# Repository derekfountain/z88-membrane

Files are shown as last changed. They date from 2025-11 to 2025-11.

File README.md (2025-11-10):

# A new keyboard membrane for the Z88 laptop

The Z88 laptop from 1988 is well out of support. :)
I have a couple of them, and although they're working fine, I've
always been a bit nervous of that keyboard membrane. Membranes on
machines like the ZX Spectrum have a finite life and need replacing
every so often. Would the Z88's keyboard membrane be the same?

I decided to create a new one using a flexi-PCB. I wasn't sure if this
approach would work, but I wanted to find out. So, with considerable
help from my friend Andrew Menadue, I made one. Here it is:

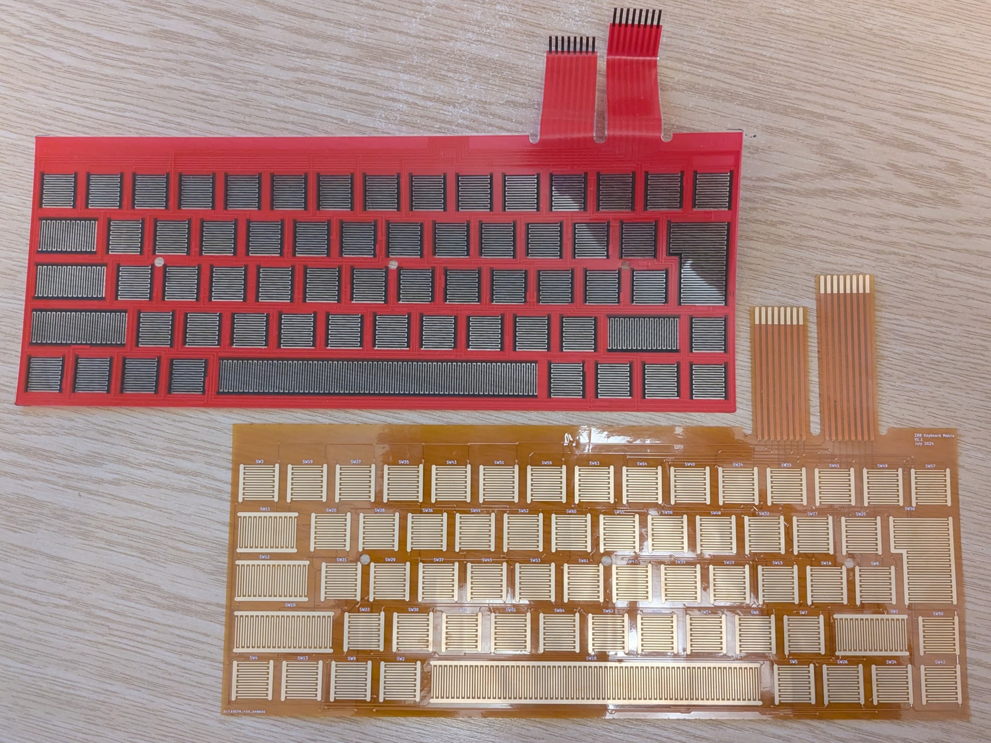
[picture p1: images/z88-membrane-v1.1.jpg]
v1.1


The original is the red one, the new one, as created by JLCPCB, is the
orange one.

The photo is of v1.1, which has the keyboard tails. v1.0 didn't have those,
which was a bit of an oversight. There are no stiffners on the tails. I
didn't know how to create them. It works without stiffners, but
you need to hold the tail right up at the gold fingers and wiggle it into
the connector. Stiffners will be added to v1.2, should I make one.

It works well, sitting perfectly in place under the Z88 rubber mat, and
conducting the carbon under-surface just as expected.

I had mine made from 0.2mm flexi-PCB, which is as thick as JLCPCB can make
them. It could stand being a bit thicker, if possible. It's a little bit
floppy compared to the original one.

[Derek Fountain](https://www.derekfountain.org/), November 2025

# Acknowledgements

[Andrew Menadue](http://trochilidae.blogspot.com/) for doing the clever
KiCAD footprint thing and the original layout of the keys.

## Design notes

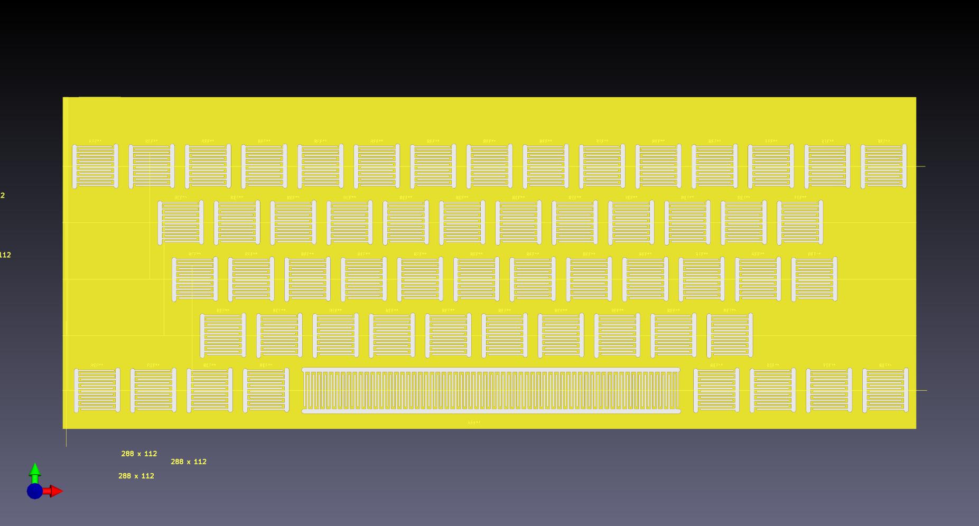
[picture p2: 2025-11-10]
images/membrane1.jpg

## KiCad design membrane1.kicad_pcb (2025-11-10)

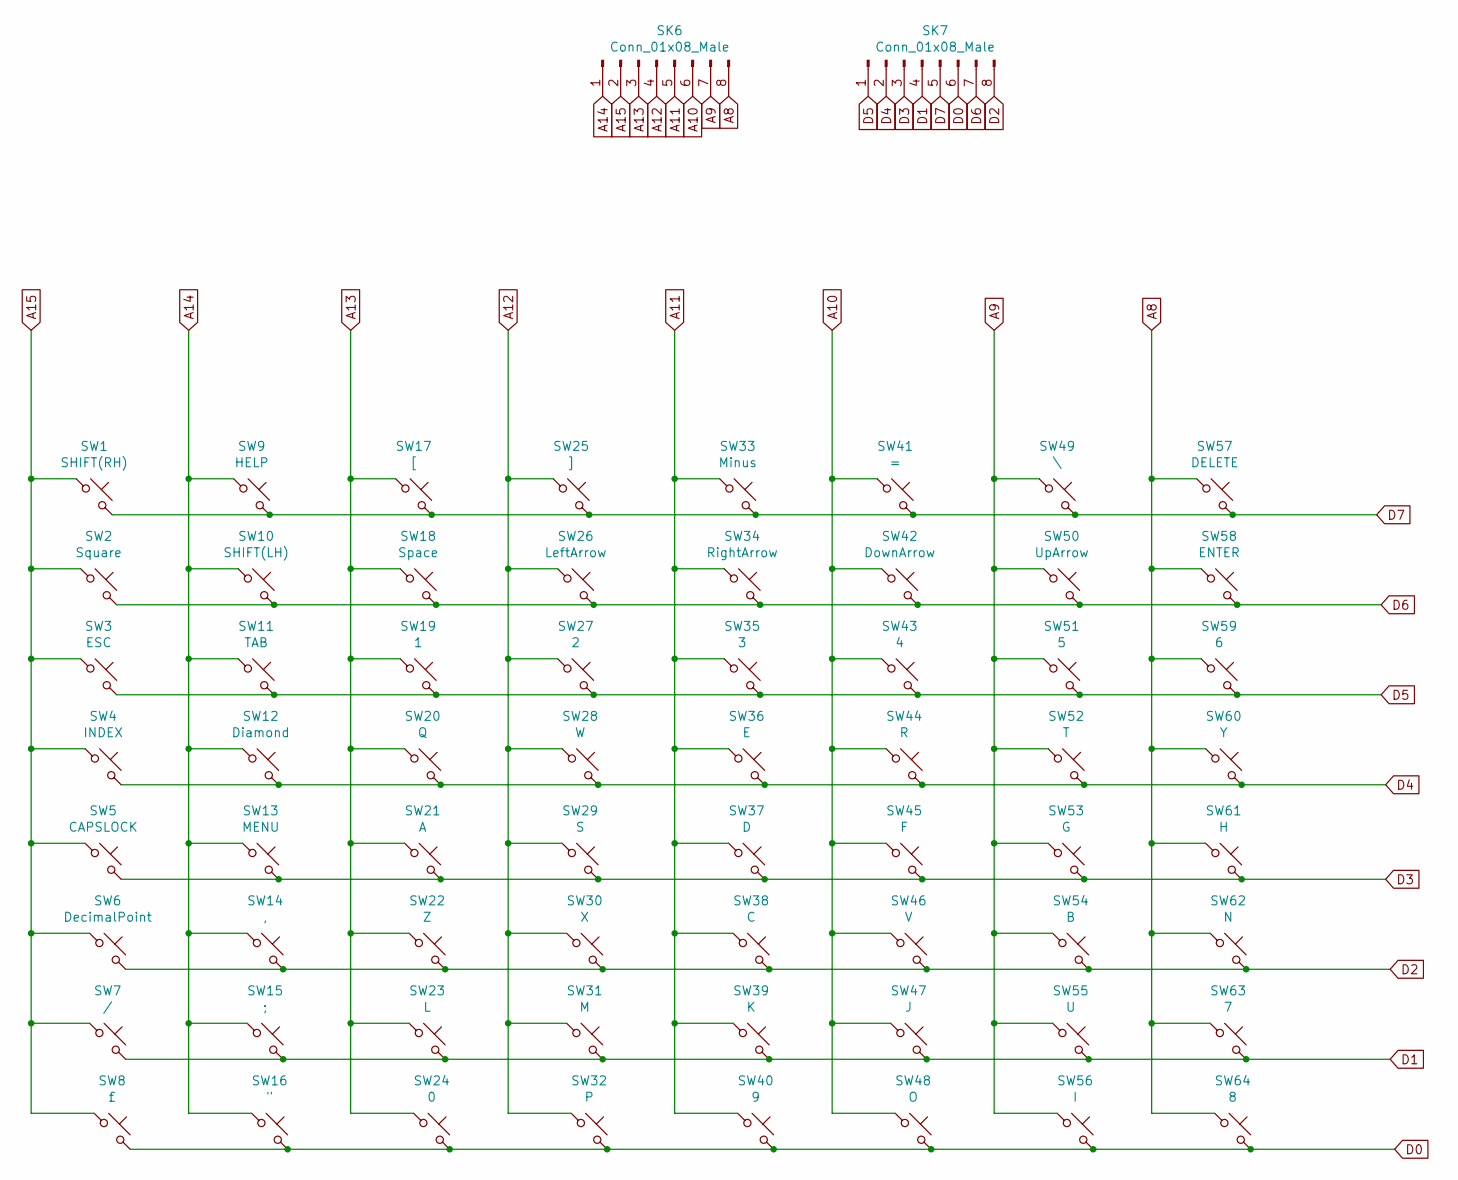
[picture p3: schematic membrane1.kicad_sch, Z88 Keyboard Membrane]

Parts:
SK6, SK7: Conn_01x08_Male; PinSocket_1x08_P2.00mm_Vertical_SMD_Pin1Left
SW1: SHIFT(RH); z88_shiftrh_pad1
SW2: Square; z88_pad1
SW3: ESC; z88_pad1
SW4: INDEX; z88_pad1
SW5: CAPSLOCK; z88_pad1
SW6: DecimalPoint; z88_pad1
SW7: /; z88_pad1
SW8: £; z88_pad1
SW9: HELP; z88_pad1
SW10: SHIFT(LH); z88_shiftlh_pad1
SW11: TAB; z88_tab_pad1
SW12: Diamond; z88_shiftrh_pad1
SW13: MENU; z88_pad1
SW14: ,; z88_pad1
SW15: ;; z88_pad1
SW16: "; z88_pad1
SW17: [; z88_pad1
SW18: Space; z88_space_pad1
SW19: 1; z88_pad1
SW20: Q; z88_pad1
SW21: A; z88_pad1
SW22: Z; z88_pad1
SW23: L; z88_pad1
SW24: 0; z88_pad1
SW25: ]; z88_pad1
SW26: LeftArrow; z88_pad1
SW27: 2; z88_pad1
SW28: W; z88_pad1
SW29: S; z88_pad1
SW30: X; z88_pad1
SW31: M; z88_pad1
SW32: P; z88_pad1
SW33: Minus; z88_pad1
SW34: RightArrow; z88_pad1
SW35: 3; z88_pad1
SW36: E; z88_pad1
SW37: D; z88_pad1
SW38: C; z88_pad1
SW39: K; z88_pad1
SW40: 9; z88_pad1
SW41: =; z88_pad1
SW42: DownArrow; z88_pad1
SW43: 4; z88_pad1
SW44: R; z88_pad1
SW45: F; z88_pad1
SW46: V; z88_pad1
SW47: J; z88_pad1
SW48: O; z88_pad1
SW49: \; z88_pad1
SW50: UpArrow; z88_pad1
SW51: 5; z88_pad1
SW52: T; z88_pad1
SW53: G; z88_pad1
SW54: B; z88_pad1
SW55: U; z88_pad1
SW56: I; z88_pad1
SW57: DELETE; z88_pad1
SW58: ENTER; z88_enter_pad1
SW59: 6; z88_pad1
SW60: Y; z88_pad1
SW61: H; z88_pad1
SW62: N; z88_pad1
SW63: 7; z88_pad1
SW64: 8; z88_pad1

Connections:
A8: SK6.8, SW57.1, SW58.1, SW59.1, SW60.1, SW61.1, SW62.1, SW63.1, SW64.1
A9: SK6.7, SW49.1, SW50.1, SW51.1, SW52.1, SW53.1, SW54.1, SW55.1, SW56.1
A10: SK6.6, SW41.1, SW42.1, SW43.1, SW44.1, SW45.1, SW46.1, SW47.1, SW48.1
A11: SK6.5, SW33.1, SW34.1, SW35.1, SW36.1, SW37.1, SW38.1, SW39.1, SW40.1
A12: SK6.4, SW25.1, SW26.1, SW27.1, SW28.1, SW29.1, SW30.1, SW31.1, SW32.1
A13: SK6.3, SW17.1, SW18.1, SW19.1, SW20.1, SW21.1, SW22.1, SW23.1, SW24.1
A14: SK6.1, SW9.1, SW10.1, SW11.1, SW12.1, SW13.1, SW14.1, SW15.1, SW16.1
A15: SK6.2, SW1.1, SW2.1, SW3.1, SW4.1, SW5.1, SW6.1, SW7.1, SW8.1
D0: SK7.6, SW8.2, SW16.2, SW24.2, SW32.2, SW40.2, SW48.2, SW56.2, SW64.2
D1: SK7.4, SW7.2, SW15.2, SW23.2, SW31.2, SW39.2, SW47.2, SW55.2, SW63.2
D2: SK7.8, SW6.2, SW14.2, SW22.2, SW30.2, SW38.2, SW46.2, SW54.2, SW62.2
D3: SK7.3, SW5.2, SW13.2, SW21.2, SW29.2, SW37.2, SW45.2, SW53.2, SW61.2
D4: SK7.2, SW4.2, SW12.2, SW20.2, SW28.2, SW36.2, SW44.2, SW52.2, SW60.2
D5: SK7.1, SW3.2, SW11.2, SW19.2, SW27.2, SW35.2, SW43.2, SW51.2, SW59.2
D6: SK7.7, SW2.2, SW10.2, SW18.2, SW26.2, SW34.2, SW42.2, SW50.2, SW58.2
D7: SK7.5, SW1.2, SW9.2, SW17.2, SW25.2, SW33.2, SW41.2, SW49.2, SW57.2

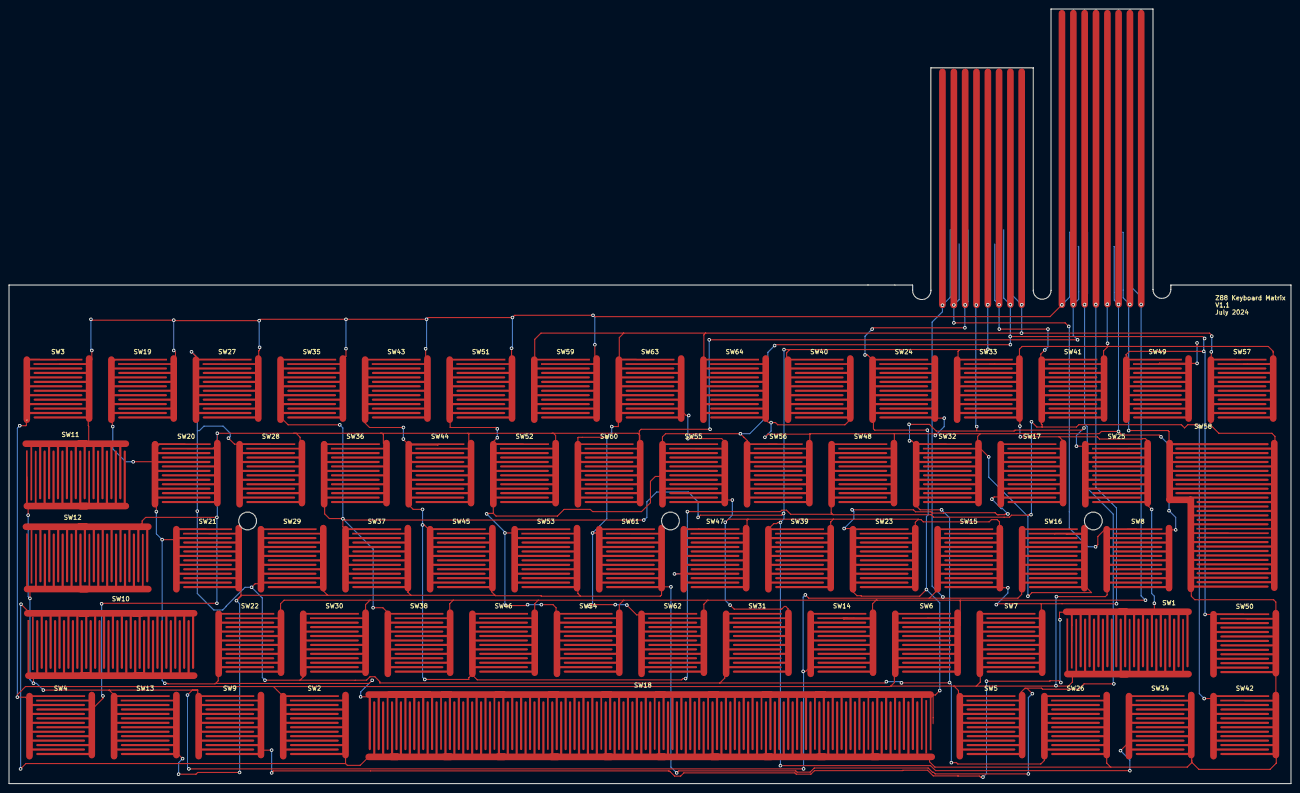
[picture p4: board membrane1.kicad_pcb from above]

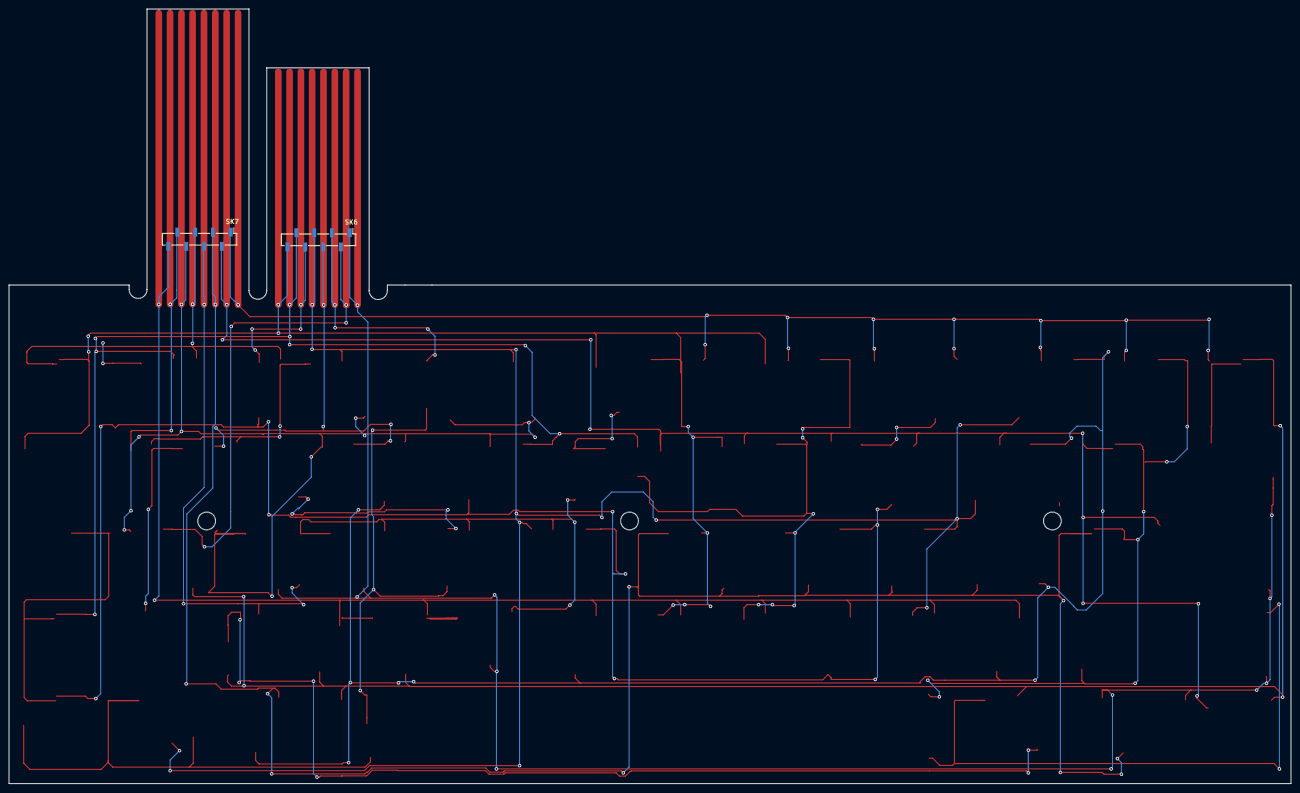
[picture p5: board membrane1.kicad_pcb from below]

Board: 2 copper layers, 288.0 x 174.0 mm, 66 parts (2 on the bottom side), 16 nets.
